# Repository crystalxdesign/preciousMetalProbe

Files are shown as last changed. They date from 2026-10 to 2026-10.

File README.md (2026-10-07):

# Pico LC metal-sample capture

A complete **Pico SDK C project for the original RP2040 Raspberry Pi Pico**,
plus a labelled USB data logger and a custom electrical wiring diagram.
This collects training data; it does not yet train or run a classifier.

## Files

- `firmware/main.c`: ADC FIFO, 16-bit DMA capture, hardware ADC stop, USB commands.
- `firmware/excite.pio`: deterministic 5 µs active-high excitation pulse.
- `firmware/CMakeLists.txt`: Pico SDK build.
- `host/capture.py`: validates records and appends labelled JSONL training data.
- `host/plot_capture.py`: inspect a captured waveform.
- `docs/preciousMetalProbe.png` and `.svg`: wiring schematic with component pin numbers.
- `docs/wiring.md`: complete net list, component list and bring-up procedure.
- `tests/test_protocol.py`: serial framing, CRC and fault-rejection tests.

## Circuit

Use the circuit in `docs/preciousMetalProbe.png`. GP15 controls the active-high
TMUX1101 switch; the switch connects +3.3 V through 330 Ω to TANK for 5 µs.
A 470 µH air-core sensing coil and 47 nF capacitor are in parallel between TANK
and buffered BIAS (~1.65 V). A second OPA2320 buffer feeds GP26 / ADC0 through
100 Ω, with 4.7 nF to AGND at the ADC pin. All analogue ICs use the Pico's 3.3 V
supply. GP15 has an external 100 kΩ pulldown to keep excitation off at reset.

Verify the waveform with an oscilloscope before connecting GP26. Both TANK and
ADC should remain comfortably within 0.3–3.0 V. The amplifier and switch inputs
must also stay within their operating ranges. If ringing is excessive, shorten
the pulse (changing the PIO delay and PULSE_US together) or increase R3.
The ADC RC network is not a strong anti-alias filter. Exclude switching
transients from fitting, and investigate any substantial high-frequency pickup.

## Capture behaviour and timing

- ADC0 only; no round-robin sampling. 500 kS/s at the default 48 MHz ADC clock.
- 2048 raw uint16 samples, retaining 12 data bits and error bit 15.
- Nominal record length: 4.096 ms; sample interval: 2 µs.
- Approximately 128 µs of pre-pulse baseline; the actual rise is a little later
  because ADC start and PIO enable are sequential CPU operations.
- PIO runs at 1 MHz and generates a 5 µs high interval, followed by low.
- A chained DMA write stops the ADC when the capture buffer is full.
- USB transmission occurs after sampling. No unsolicited captures at boot.
- At least 20 ms settling time precedes each requested capture.

**ADC/PIO alignment is estimated, not exact sample synchronisation.** They use
different clocks. `rise_us_est` and `fall_us_est` are relative to software ADC
start, using bracketed launch times and the PIO delay. `launch_bracket_us`
measures those software brackets; it is not a total timing-uncertainty bound.
Allow a few microseconds for divider phase, peripheral launch and ADC aperture.
For model inputs, find/refine the pulse boundary in the waveform and crop a
consistent post-pulse interval. Do not treat the header as an exact trigger index.

The plot uses nominal conversion-completion times `(index + 1) / fs`.
For voltage conversion use the measured ADC reference:
`V_TANK ≈ raw * VREF / 4096`. Subtract pre-pulse baseline to estimate the voltage
across the LC circuit. Raw counts are preserved; the RP2040's nominal 12-bit ADC
does not imply 12-bit effective accuracy or perfect linearity.

## Build from source

Install CMake, an Arm embedded GCC toolchain, Python 3, Git and a native C/C++
compiler. On Debian/Ubuntu a usual starting command is:

```sh
sudo apt install cmake build-essential gcc-arm-none-eabi libnewlib-arm-none-eabi git python3 python3-venv
git clone --branch 2.2.0 --depth 1 https://github.com/raspberrypi/pico-sdk.git
git -C pico-sdk submodule update --init lib/tinyusb
export PICO_SDK_PATH="$PWD/pico-sdk"
```

From the extracted `lc_metal_capture` directory:

```sh
cmake -S firmware -B build -DPICO_BOARD=pico -DCMAKE_BUILD_TYPE=Release -DPICO_NO_PICOTOOL=1
cmake --build build -j4
```

The tested command above builds ELF/BIN and uses the included RP2040 BIN-to-UF2
converter, avoiding an extra picotool download. Omit `-DPICO_NO_PICOTOOL=1` to use
the SDK's normal picotool UF2 generation instead; it can fetch/build picotool
if required (network access and a native toolchain needed).
If CMake cannot find the SDK, pass `-DPICO_SDK_PATH=/absolute/path/to/pico-sdk`.
On Windows, use the Raspberry Pi Pico SDK toolchain environment and equivalent
CMake commands; Bash `export` and `sudo apt` are Linux instructions.

Hold BOOTSEL while plugging the Pico into USB. Copy
`build/lc_metal_capture.uf2` (or the supplied prebuilt UF2) to the RPI-RP2 drive.
The board reboots and appears as a USB serial device. Use a data-capable cable.

## Collect labelled data

Create a PC Python environment:

```sh
python3 -m venv .venv
. .venv/bin/activate
python -m pip install -r host/requirements.txt
python -m serial.tools.list_ports
```

Windows activation: `.venv\Scripts\activate`; use a port such as `COM5`.
On Linux the port is commonly `/dev/ttyACM0`. Your account may need permission
to use the serial device (often membership in the `dialout` group).
Close any other serial terminal while running the logger.

With a copper specimen held flat, 5 mm from the coil:

```sh
python host/capture.py --port /dev/ttyACM0 --label copper \
  --specimen copper_01 --gap-mm 5 --orientation flat_parallel \
  --cap-nf 47 --coil-uh 470 --session bench_01 \
  --count 100 --output data/captures.jsonl
```

Collect an empty-coil baseline and other specimens into the same file:

```sh
python host/capture.py --port /dev/ttyACM0 --label empty \
  --specimen none --gap-mm 0 --session bench_01 \
  --count 100 --output data/captures.jsonl
python host/plot_capture.py data/captures.jsonl --index 0
```

For the empty label, gap 0 is a placeholder meaning "no target", not a target
touching the coil. `--cap-nf` and `--coil-uh` are operator-entered metadata;
the firmware cannot detect which capacitor or coil is fitted. Power off before
changing capacitors manually. The same firmware works at nominal 23.2, 33.9
or 49.5 kHz with 100, 47 or 22 nF respectively and the nominal 470 µH coil.

`--interval 0.05` specifies a minimum interval between requests. This is not a
guaranteed 20 frames/s: text USB transfer and host processing may take longer.
Only validated frames are saved; an integrity/hardware fault stops the run.
Completed records remain in the append-only JSONL file. Each record contains a
unique capture UUID, UTC timestamp, session, label, specimen, gap, orientation,
capacitance, coil inductance, notes, firmware metadata and all raw samples.

## Terminal commands and wire protocol

Send `h` followed by newline for help, or `c` followed by newline for one capture.
USB CDC baud setting is immaterial; the logger opens at 115200 and asserts DTR.

Each capture is `FRAME <JSON>`, then 64 `DATA <start>,<32 uint16 samples>` lines,
then `END <frame id>`. Frame IDs restart at reboot; the host UUID avoids clashes.
CRC-32/ISO-HDLC is computed over all uint16 samples in little-endian order,
including the ADC error bits, with initial/final XOR 0xffffffff. Python
`zlib.crc32(struct.pack('<2048H', *samples))` produces the same value.

Fault fields include ADC error count, near-rail count, FIFO overflow/underflow,
capture timeout and PIO pulse-completion status. Near-rail means raw ADC ≤16
or ≥4079; this is a diagnostic heuristic, not a calibrated voltage check.

## Training discipline

Start by plotting resonant frequency and decay versus label and gap. If those
measurements do not separate classes, a neural network cannot recover material
information absent from the sensor. Use a plastic jig and several distinct
specimens per metal; retain session/specimen/gap metadata. Split train/test by
physical specimen or session rather than individual repeated captures.
For a feature model, use baseline-relative frequency, decay, approximate Q,
amplitude and, later, measurements at several capacitor settings.

## Verification

```sh
python -m unittest discover -s tests -v
```

The protocol tests do not emulate the RP2040 or analogue hardware. Build and
host checks cannot replace oscilloscope verification of pulse timing, ADC
waveform range, resonance and damping on the assembled circuit.

## Primary references

- Raspberry Pi ADC/PIO/DMA SDK APIs: https://www.raspberrypi.com/documentation/pico-sdk/hardware.html
- Raspberry Pi official ADC DMA example: https://github.com/raspberrypi/pico-examples/tree/master/adc/dma_capture
- Pico pinout and analogue power: https://datasheets.raspberrypi.com/pico/pico-datasheet.pdf
- OPA2320 family pinout: https://www.ti.com/lit/ds/symlink/opa320.pdf
- TMUX1101 pinout: https://www.ti.com/lit/ds/symlink/tmux1101.pdf

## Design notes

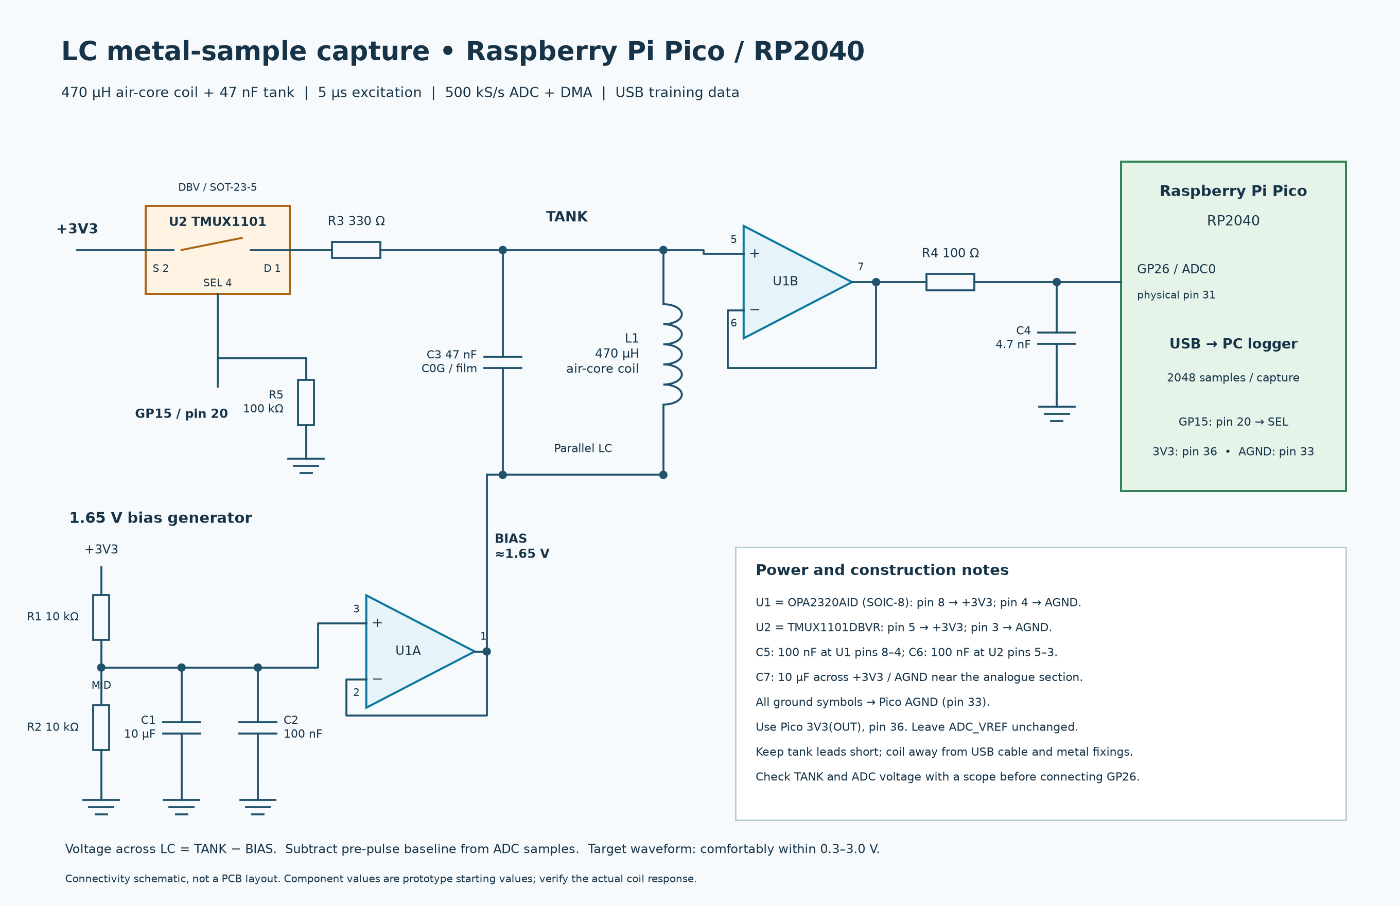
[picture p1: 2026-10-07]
docs/preciousMetalProbe.png

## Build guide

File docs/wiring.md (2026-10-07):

# Wiring and component list

Use the specified packages: **OPA2320AID, SOIC-8** (not OPA2320S), and
**TMUX1101DBVR, SOT-23-5**, with pins numbered as in their datasheets.
The schematic is a connectivity drawing, not a PCB layout or footprint guide.

## Nets

| Net | Connections |
|---|---|
| +3V3 | Pico pin 36; U1 pin 8; U2 pin 5; R1 top; U2 S pin 2; C5/C6/C7 supply ends |
| AGND | Pico pin 33; U1 pin 4; U2 pin 3; R2 bottom; C1/C2/C4/C5/C6/C7 ground ends; R5 bottom |
| MID | R1 bottom; R2 top; C1/C2 positive/signal ends; U1A + input pin 3 |
| BIAS | U1A output pin 1; U1A − input pin 2; L1 lower terminal; C3 lower terminal |
| EXCITE | Pico GP15 physical pin 20; U2 SEL pin 4; R5 top |
| SWITCH_OUT | U2 D pin 1; R3 input end |
| TANK | R3 output end; L1 upper terminal; C3 upper terminal; U1B + input pin 5 |
| BUFFER_OUT | U1B output pin 7; U1B − input pin 6; R4 input end |
| ADC_IN | R4 output end; C4 signal end; Pico GP26 / ADC0 physical pin 31 |

L1 and C3 are both connected between TANK and BIAS. Neither LC terminal is
connected directly to ground. There is no power or external signal connection
to Pico ADC_VREF. All grounds are common; route analogue returns to AGND without
running switch/USB return currents through long coil or ADC ground leads.

## Parts

| Ref | Value / part | Notes |
|---|---|---|
| U1 | OPA2320AID | Dual unity-gain-stable rail-to-rail amplifier; SOIC-8 |
| U2 | TMUX1101DBVR | Active-high analogue switch; SOT-23-5 |
| R1/R2 | 10 kΩ each | 1% or better, matched values for midrail |
| R3 | 330 Ω | Excitation resistor; increase if tank amplitude is excessive |
| R4 | 100 Ω | ADC buffer isolation |
| R5 | 100 kΩ | SEL reset pulldown |
| L1 | ~470 µH measured air-core coil | Start with 40–60 mm plastic former; adjust winding to measured value |
| C1 | 10 µF | MID filter, ≥6.3 V; if electrolytic, positive to MID |
| C2 | 100 nF | MID filter |
| C3 | 47 nF | Stable C0G/NP0 or polypropylene film; ≥16 V |
| C4 | 4.7 nF | ADC transient isolation; place at GP26 |
| C5 | 100 nF | Directly between U1 pins 8 and 4 |
| C6 | 100 nF | Directly between U2 pins 5 and 3 |
| C7 | 10 µF | Analogue supply bulk capacitor; positive to +3V3 |

Do not put a large capacitor directly on U1A's output/BIAS without checking
amplifier stability. C1/C2 filter the divider input, not the buffer output.
Keep the analogue circuit compact and the coil mechanically fixed. Avoid a
ground plane under the sensing coil and metal hardware in the sensing region.

## Bring-up

1. Leave GP26 disconnected. Inspect wiring and package orientation.
2. Connect USB power. Check +3V3, MID and BIAS; the latter two should be near 1.65 V.
3. Flash firmware. With an oscilloscope, request `c\n` and check GP15 is high
   for 5 µs and returns low. It should remain low while idle/reset.
4. Scope TANK against AGND with a high-impedance ×10 probe. Check the resting
   1.65 V and a decaying sinusoid after excitation. Expect around 33.9 kHz
   for the nominal measured L/C, modified by coil losses and nearby targets.
5. Check U1B output and ADC_IN remain within 0.3–3.0 V comfortably for all intended
   targets and gaps. Adjust R3/pulse if necessary; do not rely on input clamp diodes.
6. Connect GP26, run the logger and inspect an empty-coil waveform.
7. Remove the scope probe before final training collection if its capacitance
   materially changes the tank. Keep cabling and surroundings consistent.
8. Use a plastic jig to introduce targets and record their actual distances.

If the ring decays too quickly, check coil resistance/losses, incorrect connections,
conductive material behind the coil and unintended loading. If there is no ring,
check excitation polarity, switch supply, SEL and U1 buffer wiring. A flat ADC
trace near either rail requires correcting the hardware before collection.

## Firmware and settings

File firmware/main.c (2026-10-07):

// Original LC ring-down acquisition firmware for Raspberry Pi Pico / RP2040.
// GP15 -> TMUX1101 SEL; buffered TANK voltage -> GP26 / ADC0.
#include <stdio.h>
#include <stdint.h>
#include <string.h>
#include "pico/stdlib.h"
#include "pico/stdio_usb.h"
#include "hardware/adc.h"
#include "hardware/dma.h"
#include "hardware/pio.h"
#include "hardware/clocks.h"
#include "hardware/sync.h"
#include "hardware/regs/adc.h"
#include "excite.pio.h"

#define ADC_PIN 26u
#define EXCITE_PIN 15u
#define SAMPLE_COUNT 2048u
#define PRE_DELAY_US 128u
#define PULSE_US 5u // must match the PIO instruction's [4] delay
#define CAPTURE_TIMEOUT_US 20000u
#define SETTLE_MS 20u

static uint16_t samples[SAMPLE_COUNT];
static PIO pulse_pio = pio0;
static uint pulse_sm, pulse_offset;
static int capture_dma, stop_dma;
static uint32_t stop_cs;
static uint32_t sequence;

typedef struct {
    bool timeout, fifo_over, fifo_under, pulse_done;
    uint32_t adc_errors, rail_samples;
    double rise_us_est, fall_us_est;
    uint32_t launch_bracket_us;
} capture_info;

static void pulse_reset(void) {
    pio_sm_set_enabled(pulse_pio, pulse_sm, false);
    pio_sm_clear_fifos(pulse_pio, pulse_sm);
    pio_sm_restart(pulse_pio, pulse_sm);
    pio_sm_clkdiv_restart(pulse_pio, pulse_sm);
    pio_sm_exec(pulse_pio, pulse_sm, pio_encode_jmp(pulse_offset));
    pio_sm_set_pins_with_mask(pulse_pio, pulse_sm, 0, 1u << EXCITE_PIN);
    pio_interrupt_clear(pulse_pio, 0);
}

static void hardware_init(void) {
    // Safe low immediately; the external 100k pulldown also covers reset/boot.
    gpio_init(EXCITE_PIN);
    gpio_put(EXCITE_PIN, false);
    gpio_set_dir(EXCITE_PIN, GPIO_OUT);
    adc_init();
    adc_gpio_init(ADC_PIN);
    adc_select_input(0);
    adc_set_round_robin(0);
    adc_set_clkdiv(0); // 48MHz / 96 = 500000 samples/s
    // Retain all 12 data bits, plus the per-conversion error in bit 15.
    adc_fifo_setup(true, true, 1, true, false);
    capture_dma = dma_claim_unused_channel(true);
    stop_dma = dma_claim_unused_channel(true);

    pulse_sm = pio_claim_unused_sm(pulse_pio, true);
    pulse_offset = pio_add_program(pulse_pio, &excite_program);
    pio_sm_config c = excite_program_get_default_config(pulse_offset);
    sm_config_set_set_pins(&c, EXCITE_PIN, 1);
    sm_config_set_out_shift(&c, true, false, 32);
    sm_config_set_clkdiv(&c, (float)clock_get_hz(clk_sys) / 1000000.0f);
    pio_gpio_init(pulse_pio, EXCITE_PIN);
    pio_sm_init(pulse_pio, pulse_sm, pulse_offset, &c);
    pio_sm_set_consecutive_pindirs(pulse_pio, pulse_sm, EXCITE_PIN, 1, true);
    pulse_reset();
}

static capture_info capture(void) {
    capture_info info = {0};
    sleep_ms(SETTLE_MS);
    adc_run(false);
    while (!(adc_hw->cs & ADC_CS_READY_BITS)) tight_loop_contents();
    adc_fifo_drain();
    // W1C flags: clear before arming so errors belong to this capture.
    adc_hw->cs |= ADC_CS_ERR_STICKY_BITS;
    adc_hw->fcs |= ADC_FCS_OVER_BITS | ADC_FCS_UNDER_BITS;
    memset(samples, 0, sizeof samples);
    pulse_reset();
    pio_sm_put_blocking(pulse_pio, pulse_sm, PRE_DELAY_US - 3u);

    // A second DMA channel stops the ADC in hardware after the last sample.
    // This avoids false FIFO overflow if a USB interrupt delays the CPU.
    stop_cs = adc_hw->cs & ~(ADC_CS_START_MANY_BITS | ADC_CS_START_ONCE_BITS |
                            ADC_CS_ERR_STICKY_BITS);
    dma_channel_config s = dma_channel_get_default_config(stop_dma);
    channel_config_set_transfer_data_size(&s, DMA_SIZE_32);
    channel_config_set_read_increment(&s, false);
    channel_config_set_write_increment(&s, false);
    dma_channel_configure(stop_dma, &s, &adc_hw->cs, &stop_cs, 1, false);

    dma_channel_config c = dma_channel_get_default_config(capture_dma);
    channel_config_set_transfer_data_size(&c, DMA_SIZE_16);
    channel_config_set_read_increment(&c, false);
    channel_config_set_write_increment(&c, true);
    channel_config_set_dreq(&c, DREQ_ADC);
    channel_config_set_chain_to(&c, stop_dma);
    channel_config_set_high_priority(&c, true);
    dma_channel_configure(capture_dma, &c, samples, &adc_hw->fifo,
                          SAMPLE_COUNT, true);

    // Disable interrupts only over the launch sequence (a few us).
    // ADC and PIO have different clocks: this is NOT exact sample-edge sync.
    uint32_t irq_state = save_and_disable_interrupts();
    uint64_t a0 = time_us_64();
    adc_run(true);
    uint64_t a1 = time_us_64();
    uint64_t p0 = time_us_64();
    pio_sm_set_enabled(pulse_pio, pulse_sm, true);
    uint64_t p1 = time_us_64();
    restore_interrupts(irq_state);
    info.rise_us_est = (double)((int64_t)(p0 + p1) - (int64_t)(a0 + a1)) / 2.0
                       + PRE_DELAY_US;
    info.fall_us_est = info.rise_us_est + PULSE_US;
    info.launch_bracket_us = (uint32_t)((a1 - a0) + (p1 - p0));

    uint64_t deadline = a0 + CAPTURE_TIMEOUT_US;
    while (dma_channel_is_busy(capture_dma) ||
           (adc_hw->cs & ADC_CS_START_MANY_BITS)) {
        if (time_us_64() >= deadline) {
            info.timeout = true;
            break;
        }
        tight_loop_contents();
    }
    adc_run(false);
    if (info.timeout) {
        dma_channel_abort(capture_dma);
        dma_channel_abort(stop_dma);
    } else {
        dma_channel_wait_for_finish_blocking(stop_dma);
    }
    while (!(adc_hw->cs & ADC_CS_READY_BITS)) tight_loop_contents();
    info.fifo_over = (adc_hw->fcs & ADC_FCS_OVER_BITS) != 0;
    info.fifo_under = (adc_hw->fcs & ADC_FCS_UNDER_BITS) != 0;
    info.pulse_done = pio_interrupt_get(pulse_pio, 0);
    pulse_reset();
    adc_fifo_drain();
    for (uint i = 0; i < SAMPLE_COUNT; ++i) {
        if (samples[i] & 0x8000u) ++info.adc_errors;
        uint16_t raw = samples[i] & 0x0fffu;
        if (raw <= 16u || raw >= 4079u) ++info.rail_samples;
    }
    return info;
}

static uint32_t crc32_samples(void) {
    // Standard CRC-32/ISO-HDLC, over little-endian uint16 samples incl ERR.
    uint32_t crc = 0xffffffffu;
    for (uint i = 0; i < SAMPLE_COUNT; ++i) {
        for (uint b = 0; b < 2; ++b) {
            crc ^= (samples[i] >> (8u * b)) & 0xffu;
            for (uint k = 0; k < 8; ++k)
                crc = (crc >> 1) ^ ((crc & 1u) ? 0xedb88320u : 0u);
        }
    }
    return crc ^ 0xffffffffu;
}

static void send_frame(capture_info info) {
    uint32_t id = ++sequence;
    uint32_t fs = clock_get_hz(clk_adc) / 96u;
    printf("FRAME {\"protocol\":1,\"id\":%lu,\"n\":%u,\"fs_hz\":%lu,"
           "\"pulse_us\":%u,\"rise_us_est\":%.2f,\"fall_us_est\":%.2f,"
           "\"launch_bracket_us\":%lu,\"timeout\":%u,\"fifo_over\":%u,"
           "\"fifo_under\":%u,\"pulse_done\":%u,\"adc_errors\":%lu,"
           "\"rail_samples\":%lu,\"crc32\":%lu}\n",
           (unsigned long)id, SAMPLE_COUNT, (unsigned long)fs, PULSE_US,
           info.rise_us_est, info.fall_us_est, (unsigned long)info.launch_bracket_us,
           info.timeout, info.fifo_over, info.fifo_under, info.pulse_done,
           (unsigned long)info.adc_errors, (unsigned long)info.rail_samples,
           (unsigned long)crc32_samples());
    // Chunked text is inspectable in a serial terminal and easy to recover.
    for (uint start = 0; start < SAMPLE_COUNT; start += 32u) {
        printf("DATA %u", start);
        for (uint i = start; i < start + 32u && i < SAMPLE_COUNT; ++i)
            printf(",%u", (unsigned)samples[i]);
        putchar('\n');
    }
    printf("END %lu\n", (unsigned long)id);
    fflush(stdout);
}

int main(void) {
    hardware_init();
    stdio_init_all();
    // No unsolicited captures. Host requests one frame at a time with 'c\n'.
    char command[16];
    uint pos = 0;
    bool overflow = false;
    while (true) {
        if (!stdio_usb_connected()) { pos = 0; overflow = false; sleep_ms(10); continue; }
        int ch = getchar_timeout_us(10000);
        if (ch == PICO_ERROR_TIMEOUT) continue;
        if (ch == '\r') continue;
        if (ch == '\n') {
            command[pos] = '\0';
            if (!overflow && strcmp(command, "c") == 0) send_frame(capture());
            else if (!overflow && strcmp(command, "h") == 0) {
                puts("INFO lc_metal_capture protocol=1 c=capture h=help GP15=pulse GP26=ADC0");
                fflush(stdout);
            } else puts("ERROR command; use c or h");
            pos = 0; overflow = false;
        } else if (pos + 1u < sizeof command) command[pos++] = (char)ch;
        else overflow = true;
    }
}

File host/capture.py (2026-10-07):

#!/usr/bin/env python3
"""Request Pico LC captures, validate framing/CRC, append labelled JSONL."""
import argparse
import json
import struct
import time
import uuid
import zlib
from datetime import datetime, timezone
from pathlib import Path


def read_frame(port, timeout=15.0):
    deadline = time.monotonic() + timeout
    header = None
    samples = []
    while time.monotonic() < deadline:
        raw = port.readline()
        if not raw:
            continue
        try:
            line = raw.decode("ascii").strip()
        except UnicodeDecodeError as exc:
            raise ValueError("Non-ASCII serial data; reconnect and retry") from exc
        if line.startswith("ERROR "):
            raise ValueError(line)
        if line.startswith("FRAME "):
            if header is not None:
                raise ValueError("New frame before previous END")
            header = json.loads(line[6:])
            if header.get("protocol") != 1 or header.get("n") != 2048:
                raise ValueError("Unsupported protocol or sample count")
            if not 1 <= header.get("fs_hz", 0) <= 500000:
                raise ValueError("Invalid sampling rate")
        elif line.startswith("DATA "):
            if header is None:
                raise ValueError("DATA without FRAME")
            parts = [int(x) for x in line[5:].split(",")]
            if len(parts) < 2 or parts[0] != len(samples):
                raise ValueError("Missing/duplicate/out-of-order DATA")
            if any(not 0 <= x <= 65535 for x in parts[1:]):
                raise ValueError("Sample outside uint16 range")
            samples.extend(parts[1:])
            if len(samples) > header["n"]:
                raise ValueError("Too many samples")
        elif line.startswith("END "):
            if header is None or int(line[4:]) != header["id"]:
                raise ValueError("END frame ID mismatch")
            if len(samples) != header["n"]:
                raise ValueError("Incomplete frame")
            payload = struct.pack("<" + "H" * len(samples), *samples)
            if zlib.crc32(payload) != header["crc32"]:
                raise ValueError("CRC mismatch")
            if header.get("timeout") or header.get("fifo_over") or header.get("fifo_under"):
                raise ValueError("Firmware reports capture/DMA/FIFO failure")
            if not header.get("pulse_done"):
                raise ValueError("Excitation pulse did not complete")
            if header.get("adc_errors") or any(x & 0x8000 for x in samples):
                raise ValueError("ADC conversion error")
            if any(x & 0x7000 for x in samples):
                raise ValueError("Unexpected reserved ADC bits")
            if header.get("rail_samples") or any(x <= 16 or x >= 4079 for x in samples):
                raise ValueError("ADC near a rail; check waveform before collecting data")
            return header, samples
        # INFO/help/startup text is harmless and ignored.
    raise TimeoutError("No complete frame received within timeout")


def main():
    p = argparse.ArgumentParser(description=__doc__)
    p.add_argument("--port", required=True, help="e.g. /dev/ttyACM0 or COM5")
    p.add_argument("--label", required=True, help="e.g. copper, aluminium, empty")
    p.add_argument("--specimen", required=True, help="Physical specimen ID; use none for empty")
    p.add_argument("--gap-mm", type=float, required=True)
    p.add_argument("--orientation", default="flat_parallel")
    p.add_argument("--cap-nf", type=float, default=47.0)
    p.add_argument("--coil-uh", type=float, default=470.0, help="Measured empty-coil value if known")
    p.add_argument("--session", default=None, help="Collection-session ID")
    p.add_argument("--notes", default="")
    p.add_argument("--count", type=int, default=100)
    p.add_argument("--interval", type=float, default=0.05, help="Minimum seconds between requests")
    p.add_argument("--output", type=Path, default=Path("data/captures.jsonl"))
    a = p.parse_args()
    if a.count < 1 or a.interval < 0 or a.gap_mm < 0 or a.cap_nf <= 0 or a.coil_uh <= 0:
        p.error("Count/capacitance/inductance must be positive; gap/interval nonnegative")
    import serial  # pyserial; imported here so protocol tests need no serial device
    a.output.parent.mkdir(parents=True, exist_ok=True)
    session = a.session or datetime.now(timezone.utc).strftime("%Y%m%dT%H%M%SZ")
    with serial.Serial(a.port, 115200, timeout=0.25, write_timeout=5) as port:
        # USB CDC ignores baud rate. DTR asserted by pyserial enables stdio.
        time.sleep(1.0)
        port.reset_input_buffer()
        with a.output.open("a", encoding="utf-8") as out:
            for i in range(a.count):
                started = time.monotonic()
                port.write(b"c\n")
                port.flush()
                header, raw = read_frame(port)
                record = {
                    "capture_uuid": str(uuid.uuid4()),
                    "utc": datetime.now(timezone.utc).isoformat(),
                    "session": session, "label": a.label, "specimen": a.specimen,
                    "gap_mm": a.gap_mm, "orientation": a.orientation,
                    "cap_nf": a.cap_nf, "coil_uh": a.coil_uh, "notes": a.notes,
                    "firmware": header, "samples": raw,
                }
                out.write(json.dumps(record, separators=(",", ":")) + "\n")
                out.flush()  # completed records survive an interrupted run
                print(f"{i+1}/{a.count}: {a.label} specimen={a.specimen} frame={header['id']}")
                remaining = a.interval - (time.monotonic() - started)
                if remaining > 0:
                    time.sleep(remaining)
    print(f"Saved {a.count} validated captures to {a.output}")


if __name__ == "__main__":
    try:
        main()
    except (ValueError, TimeoutError) as exc:
        raise SystemExit(f"Capture stopped: {exc}. Earlier completed records remain saved.")
